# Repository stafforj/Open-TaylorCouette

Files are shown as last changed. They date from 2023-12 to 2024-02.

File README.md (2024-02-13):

# _OpenTCF_: Accessible Taylor-Couette flow experiments and numerical models

_Open-source tools that can be used to explore the fluid dynamics of Taylor-Couette flows. The repository includes build instructions for a low-cost experiment (e.g., as a demonstrator in education), and a LES model for predicting detailed flow field information._ 

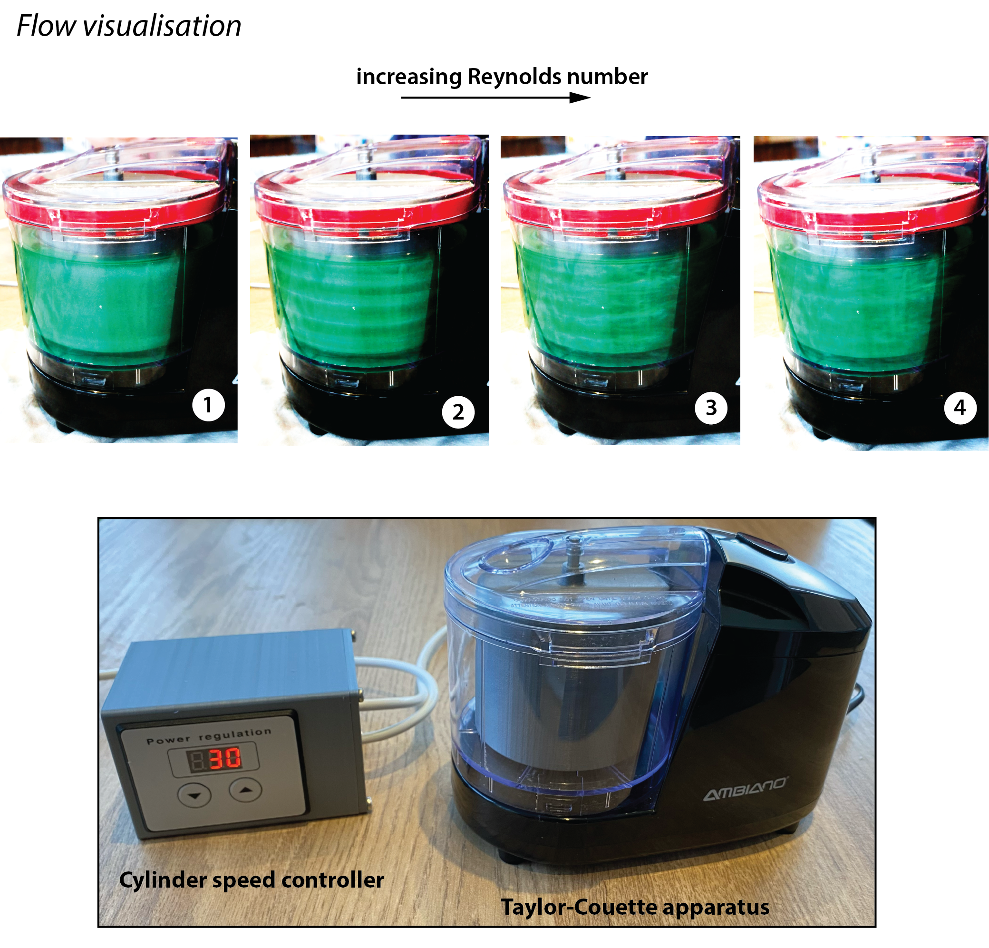
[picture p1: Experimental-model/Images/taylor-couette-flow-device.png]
TCdevice


The experiment is capable of generating a wide range of hydrodynamic conditions and flow instabilities. As evidenced by the sweep of Reynolds number above (where $Re = \frac{\omega r_i d}{\nu}$, $\omega$ and $r_i$ are rotational speed and radius of the inner cylinder, $d$ is the fluid gap, and $\nu$ is the kinematic viscosity of the liquid). The flow and Taylor vortices were visualised using a water-based rheoscopic fluid, colored using food dye. Another example is shown in the short clip below.  

TCgif

The Taylor vortex flow is apparent above, and the characteristic pattern or "bands" are also revealed when taking an ensemble-average of the video frames (greyscale image below is an average of N = 1300 frames). The profile of image intensity is plotted adjacent to this frame-average, indicating the transition between bands which occurs in a repeatable pattern (away from the liquid-gas interface and cylinder base).  

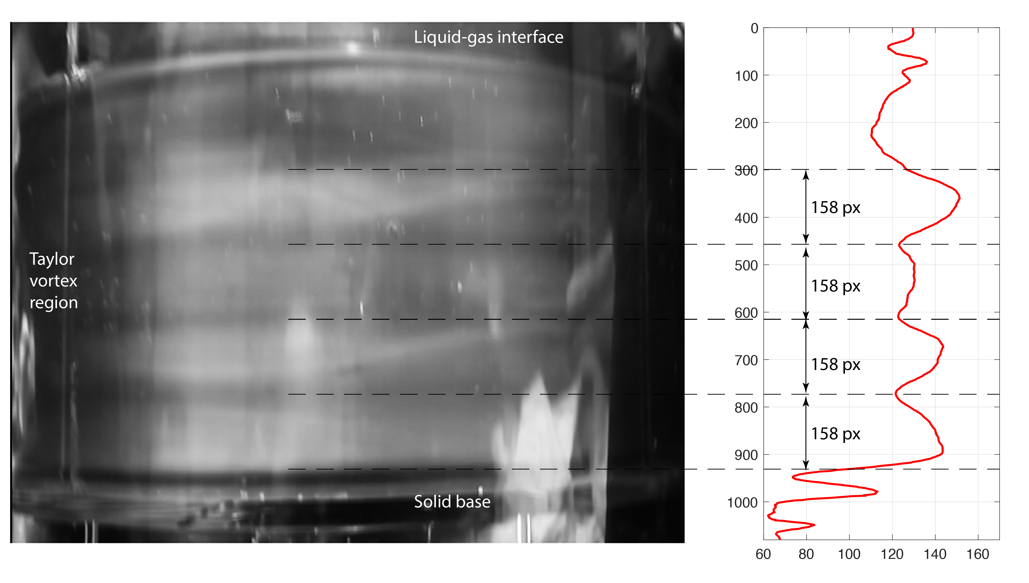
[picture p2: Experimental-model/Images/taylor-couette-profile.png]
TCprofile


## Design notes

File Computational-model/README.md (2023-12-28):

# Model description

This numerical model simulates Taylor-Couette flow using Large-Eddy Simulations. This solves the filtered continuity and Navier-Stokes equations which resolve the turbulent motion down to a point (defined by a top-hat filter $\Delta = V^{1/3}$ based on the cell volume, $V$). A wall adapting local eddy-viscosity (WALE) approach is implemented for the sub-grid-scale eddy-viscosity.

This repository includes the complete OpenFOAM (v4) case file configured for a validation test case we performed in our previously published work:

> Stafford, J., Uzo, N., Farooq, U., Favero, S., Wang, S., Chen, H-H., L'Hermitte, A., Petit, C., Matar, O. **Real-time Monitoring and Hydrodynamic Scaling of Shear Exfoliated Graphene**. _2D Materials._ 2021;8:025029 [doi:10.1088/2053-1583/abdf2f](https://doi.org/10.1088/2053-1583/abdf2f).

All details on the LES model and its usage are available in this open-access manuscript and the associated supplementary information. The OpenFOAM case can be modified to match your own geometry and operating parameters. For example, it can be used to match the [experimental model](https://github.com/stafforj/Taylor-Couette-Flow/tree/main/Experimental-model) also described in this repository. To this end, the model has been configured for generalised use. Variations to geometry, mesh parameters, Reynolds number and fluid properties are performed within the [/system/cylinderRe](./TaylorCouette-LES/system/cylinderRe) text file.  

Below shows a comparison between this model and other experimental and DNS studies for angular momentum (left) and root-mean-square azimuthal velocity fluctuation profiles across the fluid gap. This was used to refine the sub-grid-scale model coefficient ($C_w$).

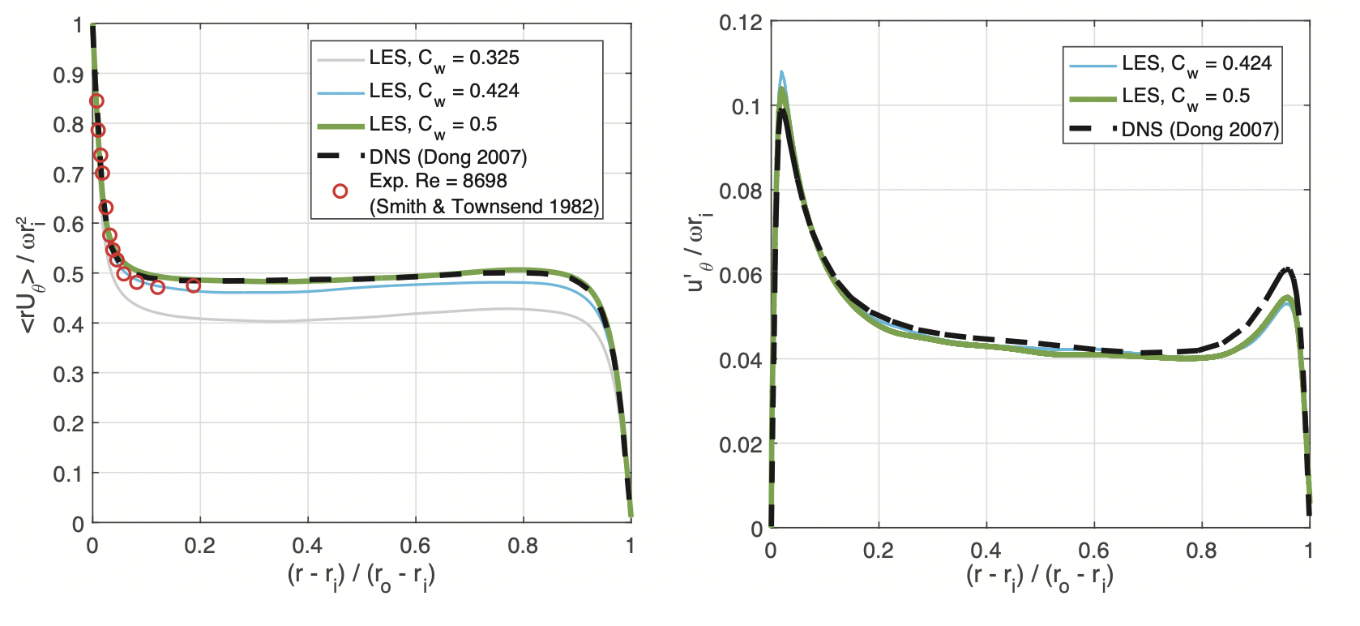
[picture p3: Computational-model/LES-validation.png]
LES-validation


Below are two snapshots of the flow field predicted using Direct Numerical Simulations (left) and this LES model (right). This result is presented as Figure S7 in our previous work referenced above ([doi:10.1088/2053-1583/abdf2f](https://doi.org/10.1088/2053-1583/abdf2f)).

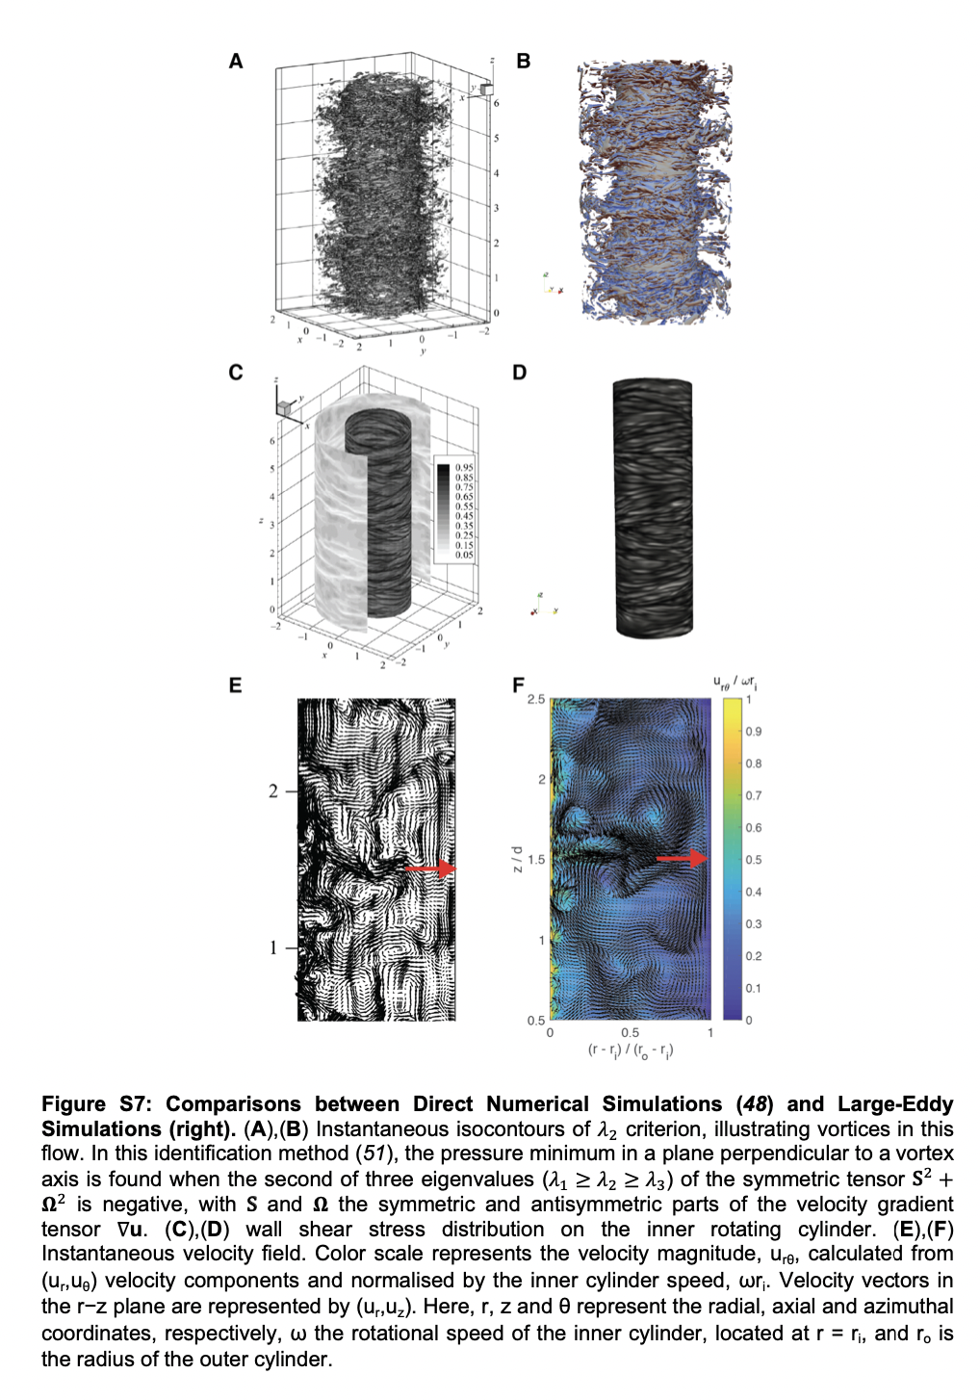
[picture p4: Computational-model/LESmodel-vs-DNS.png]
LESvsDNS


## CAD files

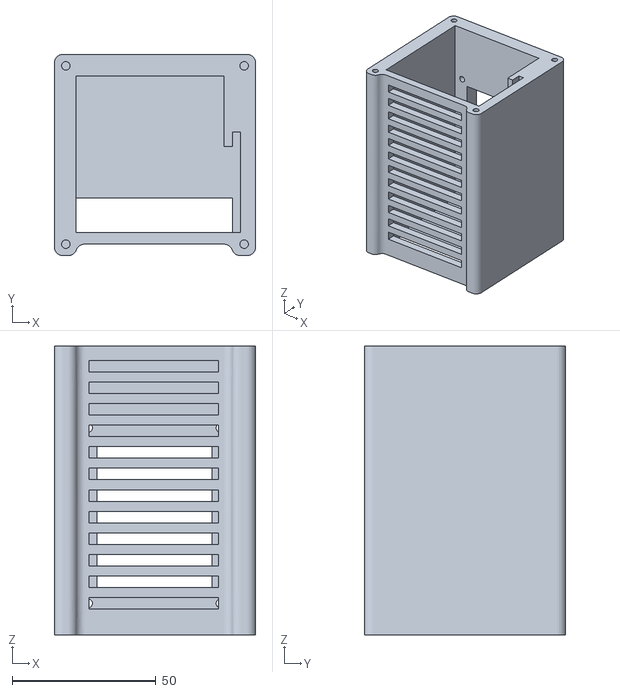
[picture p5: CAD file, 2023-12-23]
Experimental-model/CAD/motor-control-box.stl
70.0 x 70.0 x 100.5

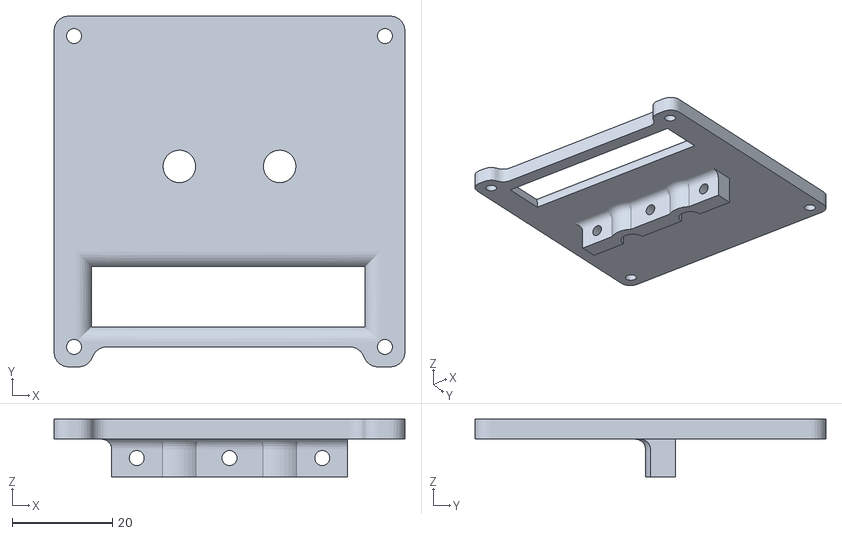
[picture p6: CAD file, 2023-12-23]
Experimental-model/CAD/motor-control-box-top.stl
70.0 x 70.0 x 11.5

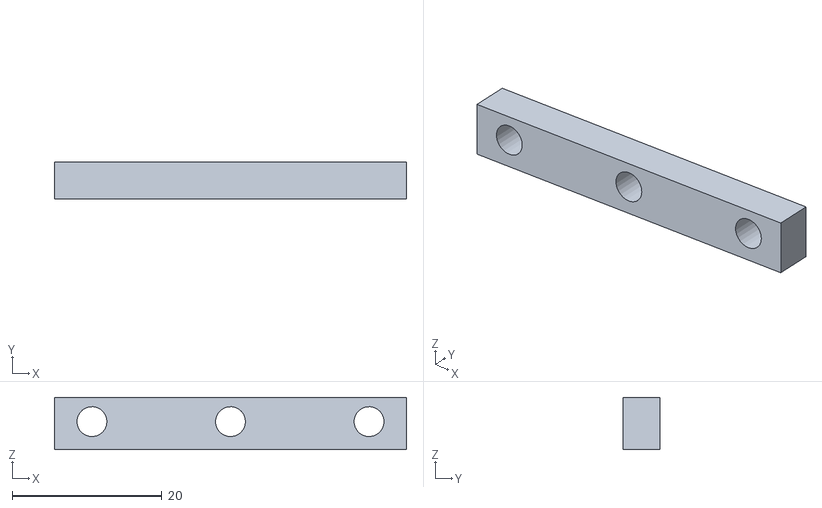
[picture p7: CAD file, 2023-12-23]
Experimental-model/CAD/motor-control-box-wire-clamp.stl
47.0 x 5.00 x 7.00

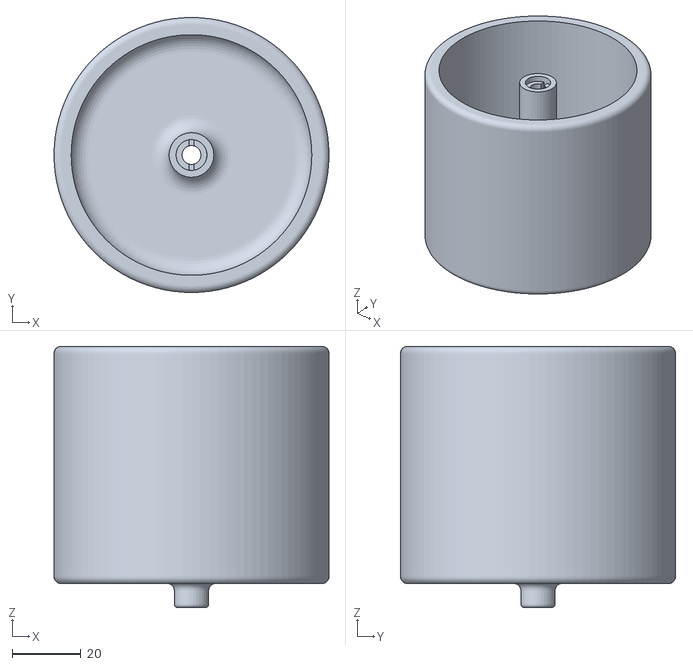
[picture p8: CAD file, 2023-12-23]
Experimental-model/CAD/inner-cylinder-d80mm.stl
80.0 x 80.0 x 76.0

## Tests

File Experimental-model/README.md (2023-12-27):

# Build instructions

This section presents the concept, bill of materials, physical construction, wiring, and device assembly for a low-cost Taylor-Couette flow visualisation experiment.

## Concept

The basic components for a Taylor-Couette apparatus are a stationary outer cyliner, a rotating inner cylinder, and a motor to control the rotational speed of the inner cylinder. While this is a simple configuration in principle, the cost of this type of design can be significant (~£1000's). Furthermore, implementing a design which has adaptable settings such as speed and cylinder diameter adds complexity, cost, and may require extra technical assistance when disassembling/assembling the apparatus. Our device concept was based on a number of requirements:

> - Create a Taylor-Couette experiment that is accessible, low-cost and affordable (a target of under £50 was set)
> - Allow users to modulate flow regimes using rotational speed control of the inner cylinder
> - Extend the flow parameter space further by facilitating "hot-swappable" innner cylinders (no tools required)

To achieve an affordable design, and minimise the number of parts required for manufacturing, we utilised an off-the-shelf mini food chopper appliance which can be purchased for < £15. These choppers have some of the core components for the device, including a motor and a clear outer bowl that can facilitate flow visualisation.

The main challenges which can restrict the chopper options are: (i) if the bowl has internal baffles, these can disrupt the Taylor-Couette flow; and (ii) if the bowl has a variable diameter along its height. Therefore, the recommendation is to source a mini chopper which has a near constant bowl diameter, and which has none or very small baffle width (note these baffles could be removed using a dremel tool). We chose an Ambiano mini chopper which fits this description and is shown below. The outer diamater varied from 101 mm (top) to 98 mm (base), and the four small baffles were < 0.6 mm width. Using an inner cylinder of diameter 80 mm, the fluid gap width ($d$) varied from 9 mm to 10.5 mm along the fluid height.  

The second advantage of using this type of appliance is it allowed straightforward integration of the "hot-swappable" cylinder concept. Mini food choppers typically have removable inner blades to facilitate their cleaning after use. The stainless steel blades are rotated from below and held in place from above using an alignment pin attached to the lid of the bowl. We took advantage of this and created an inner cylinder which slots onto the motor shaft. This is shown in the schemtic below. The cylinder rotates about the axis and is held concentric with the outer cylinder using this alignment pin on the lid. 

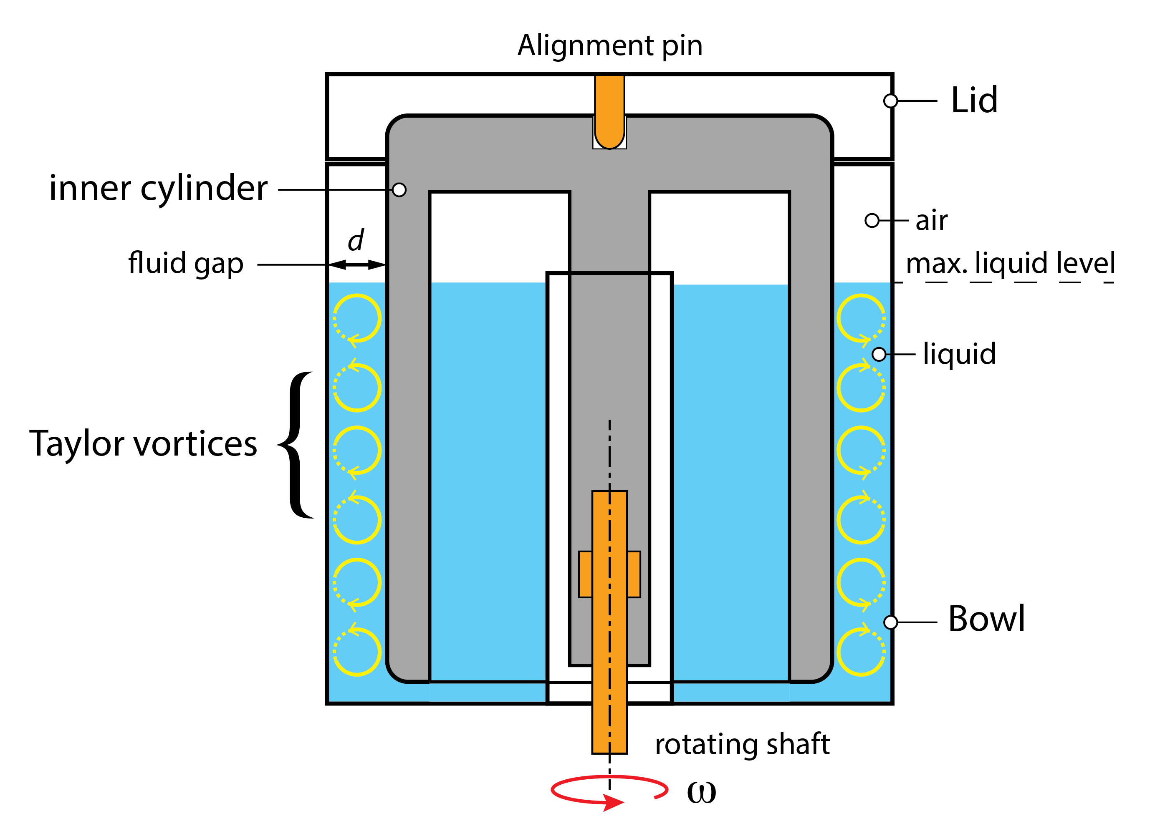
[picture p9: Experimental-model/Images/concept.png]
concept


The final design consists of three core components shown here: (i) an interchangeable inner cylinder; (ii) motor + clear outer cylinder (mini chopper); and (iii) module for controlling cylinder speed.

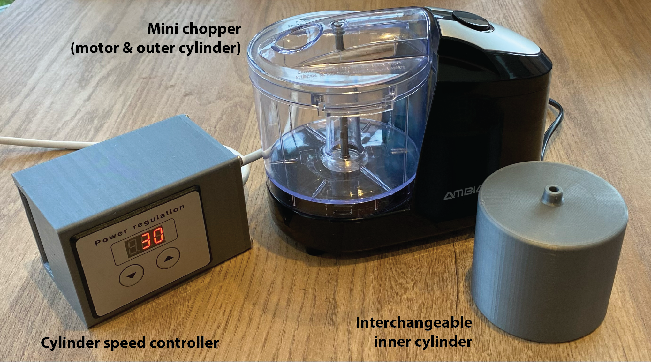
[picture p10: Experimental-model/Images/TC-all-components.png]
components


Image of the mini chopper used in this build
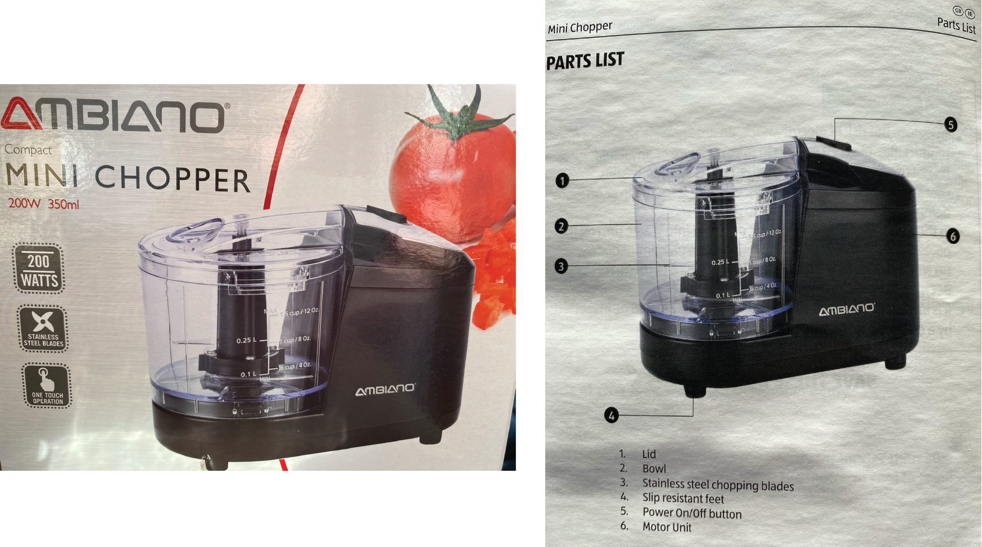
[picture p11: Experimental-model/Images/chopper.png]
chopper


## Bill of Materials

|Name |QTY|Description |
|:---|:-:|:---|
|Mini food chopper|1  |Mini food chopper. There are numerous choices. This build uses a 200W Ambiano purchased from Aldi.|
|[Motor controller board](https://www.amazon.co.uk/Controller-Regulator-Digital-Voltage-Thermostat/dp/B07SW4LXY9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)|1  |Bidirectional thyristor. The one used here is rated for very high power (up to 10kW) as I already had one available. Many other options are available with lower current/power rating that can be used.|
|2 or 3-core cable|1  |No. of cores and length depending on requirements. 1.5 mm$^2$ copper cores, or selected based on current requirements.|
|M3.5 screws|4  |12 mm long, for mounting top cover of motor controller to the enclosure body.|
|Misc.| | <ul><li>Wiring and heat shrink</li><li>Soldering Iron and solder</li><li>Glue</li><li>Electrical hand drill and drill bits</li></ul>|

## Construction
The device is constructed from a mini food chopper, modified to rotate a cylinder at controllable rotational speeds.

construction

## Wiring
Mini food choppers like the one used in this build have an on/off switch, a safety switch that ensures it cannot be operated without the lid in place, and a motor which rotates at a fixed speed. These components are all retained for the Taylor-Couette device. The motor is powered from mains AC voltage (240V). Variable speed is achieved by controlling the power to the motor from 0-100%, where 100% is achieved at the mains AC voltage. This was done by wiring in a bidirectional thyristor on the mains cable line before it enters the appliance. This is shown below in the wiring schematic and the assembly images (1-6) for the motor control module below. Note there is no need to disassemble the appliance casing at any point of this build. 

> [!WARNING]
> Working with AC can be dangerous. Make sure to take all precautions when making modifications and ensure everything is unplugged and grounded.

A heat sink is mounted to the TRIAC and is used to passively cool the device. An enclosure is used to avoid exposure to high temperatures and mount the display and power control buttons. To ensure cooling is not affected by the enclosure, the ventilation is designed to allow the user to orient the controller in any direction (horizontally or vertically) without introducing thermal issues. Note that this TRIAC controls power not speed, and we have observed that the 0-100% scale is non-linear. It is recommended to take measurements of cylinder speed (e.g. using a tachometer) to understand how the change in input power affects speed. This is, of course, essential for defining the correct Reynolds number ($Re = \omega r_i d / \nu$).   

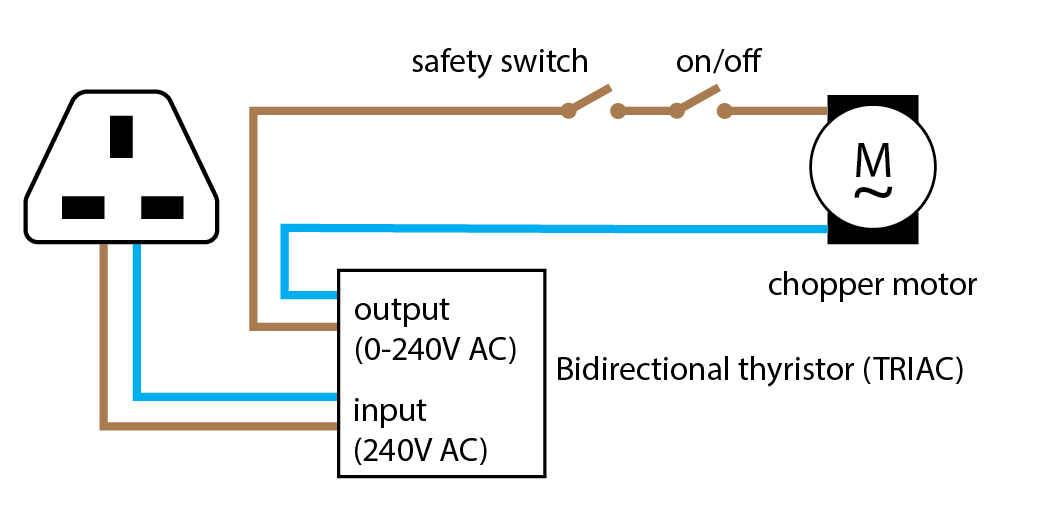
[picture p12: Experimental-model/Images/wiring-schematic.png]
schematic


Motor and cylinder control module
motorcontrol

Module enclosure and ventilation
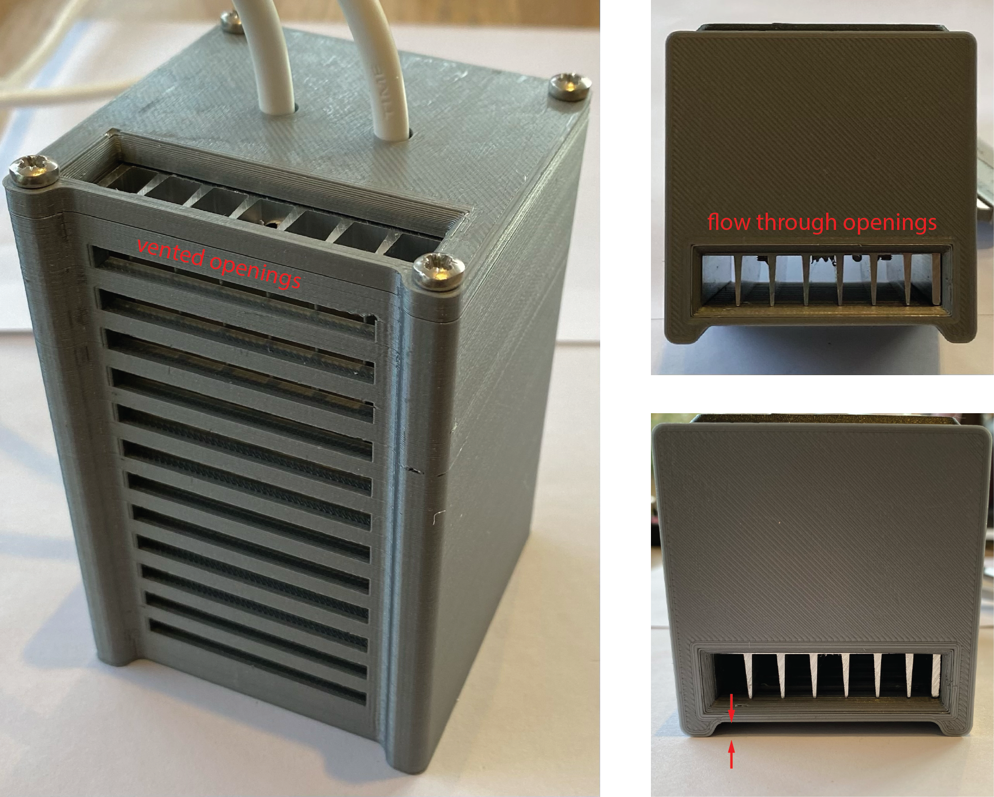
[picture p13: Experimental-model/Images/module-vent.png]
vents


## Device assembly for experiments

Four steps are involved for assembling the device prior to experiment. These are shown below (1-4). Between steps 2 and 3, the liquid is added to the vessel. Note there will be a maximum liquid level that avoids leaks (see _Concept_ schematic above). The manufacturer usually prints this on the bowl for the chopper, however, it is important to check this again for the Taylor-Couette set-up before performing experiments.

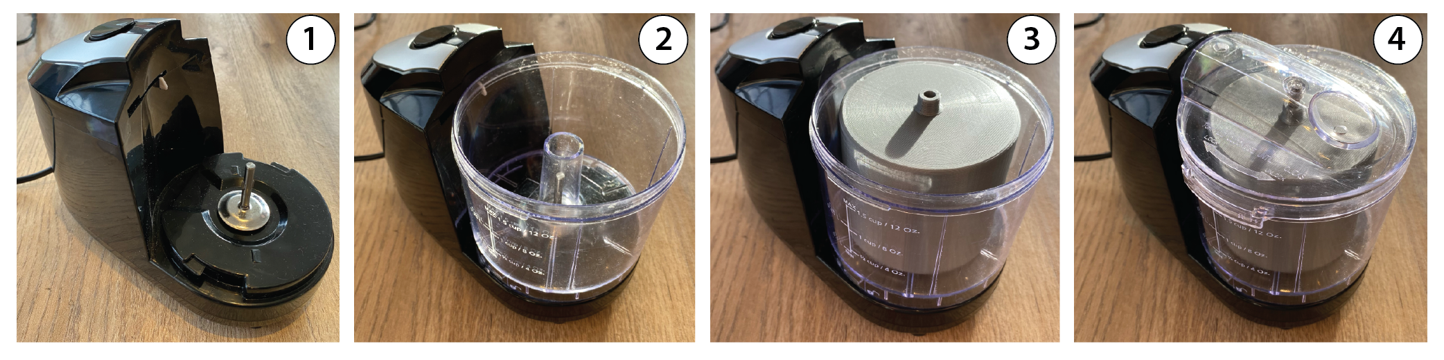
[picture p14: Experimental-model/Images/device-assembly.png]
assembly


> [!TIP]
> Check out our group's repositories on [UoB Mechanochemical Systems](https://github.com/uob-mechanochemical-systems). It includes a repository from our _OpenLPE_ project, which implements automatic [speed control for mechanochemical mixers](https://github.com/uob-mechanochemical-systems/PID-Blender). This details how to implement PID control for AC motors inside kitchen blenders, and could be extended to this work if interested in adding closed-loop speed control for the Taylor-Couette experimental model described here. 

Further information on the _OpenLPE_ project is available through our open-access article:

>  Perez-Alvarez, D., Brown, J., Stafford, J. **Modification of kitchen blenders into controllable laboratory mixers for mechanochemical synthesis of atomically thin materials**. _HardwareX_. 2023;16:e00471 [doi:10.1016/j.ohx.2023.e00471](https://doi.org/10.1016/j.ohx.2023.e00471).
